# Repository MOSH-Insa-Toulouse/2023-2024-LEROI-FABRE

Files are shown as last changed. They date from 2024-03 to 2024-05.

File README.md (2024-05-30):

# Projet MOSH
## Par Quentin et Laetitia 🥇
### ~~Le meilleur binôme~~ (il faut pas le dire) 



Cohésion d'équipe ☑️
## Diagramme du projet
```mermaid
graph TD;
    A[Capteur Graphite]-->B((Arduino Uno));
    F[Capteur Flex]-->B((Arduino Uno));
    G[Potentiomètre]-->B((Arduino Uno));
    B((Arduino Uno))-->D[Ecran LCD];
    B((Arduino Uno))-->C[Module Bluetooth];
    C[Module Bluetooth]-.->E[App Android];

```

<details>
<summary>  Etapes du projet MOSH :tada:  </summary>
  
  - [x] Attribution des inputs de l'arduino aux différents capteurs
  - [X] Electronique Analogique
  - [x] Schématique KiCad  
  - [x] Routage KiCad
  - [x] Impression du cricuit
  - [x] Percage
  - [X] Montage des capteurs sur le circuit imprimé (par Cathy, MERCIII)
  - [X] Code Arduino
  - [X] App Android
  - [X] Création du banc de test
  - [X] Création de la datasheet
        
</details>

# Quel est ce projet ?

Ce projet consiste en...

<details>
<summary> la création d'un capteur Graphite. </summary>
Un capteur graphite, c'est tout simplement un morceau de papier où l'on colorie une zone à l'aide d'un crayon à papier. Il permet de mesurer des variations de résistance lorqu'on le déforme. Voici la forme de capteur que nous utilisons : 

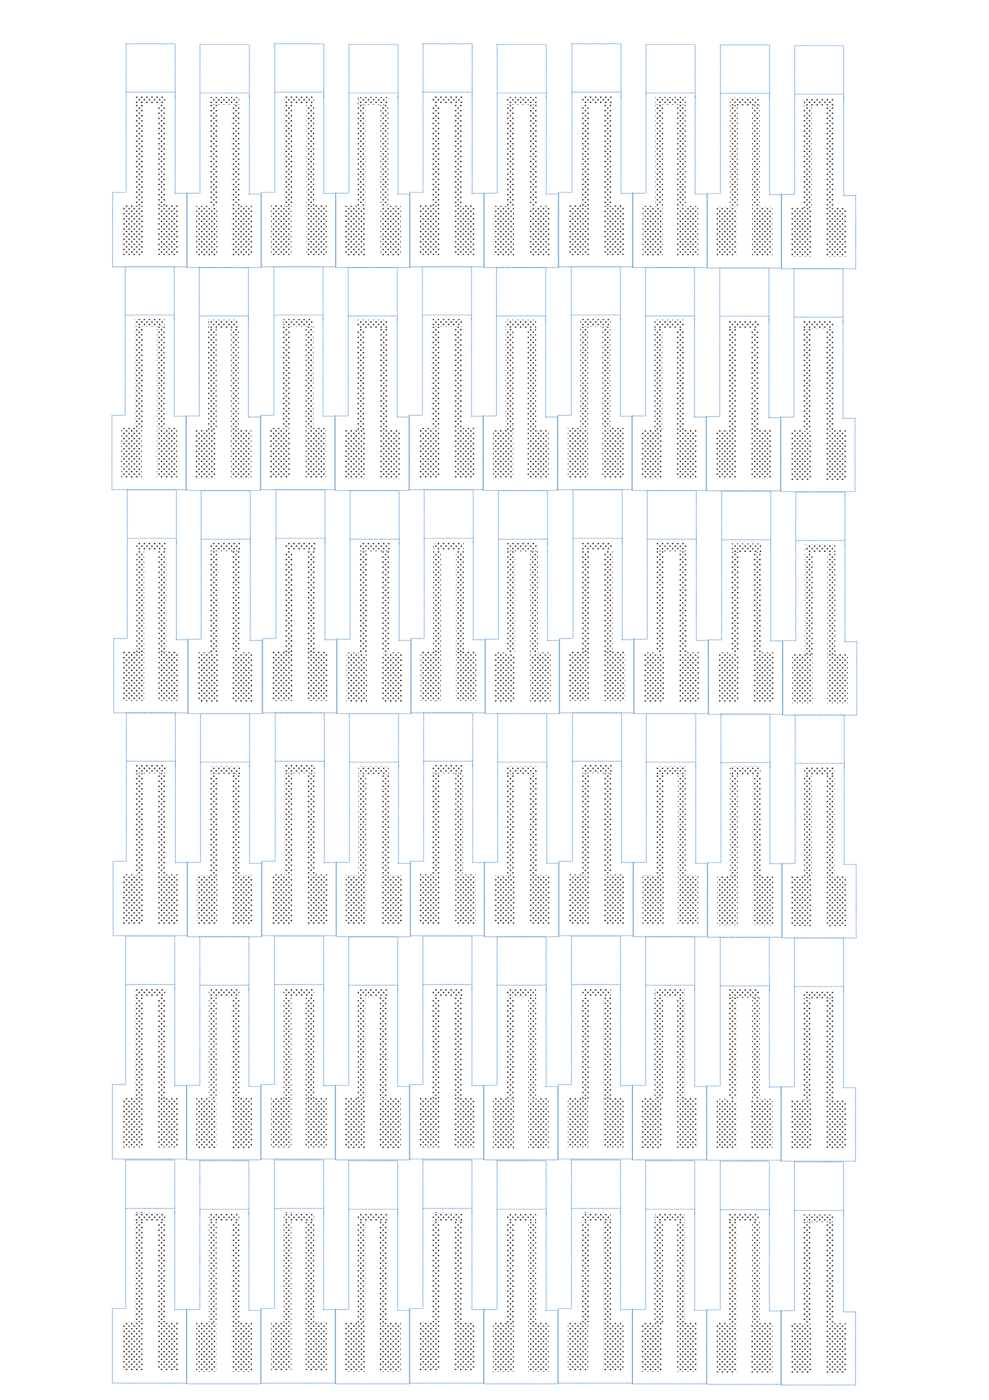
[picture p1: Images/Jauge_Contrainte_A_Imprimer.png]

</details>

<details>
<summary> la création d'un shield Arduino. </summary>
Cela permet d'effectuer les acquisitions des données envoyées par notre capteur (des variations de tensions que nous pouvons traduire en résistance !). 
Nous y implémenterons également un capteur Flex dont voici la datasheet : (insérer la datasheet), un écran LCD pour afficher les données du capteur graphite ou du capteur flex, un potentiomètre qui permettra à l'utilisateur de naviguer dans un menu qui permet d'afficher les données du capteur graphite ou du capteur flex, un potentiomètre numérique qui permettra d'ajuster une résistance pour la maniulation des données du capteur graphite,... 

Pour cela, il nous faut créer le shield sous KiCad, le faire imprimer, percer le trous, et y monter nos capteurs.
</details>

<details>
<summary> la création d'un code Arduino. </summary>
Le code permettra de commander le microcontrôleur Arduino Uno : gestion des données, commnication Bluetooth (voir App android), choix de la résistance du potentiomètre numérique, affichage sur l'écran LCD...
</details>

<details>
<summary> la création d'une App Android. </summary>
Notre projet s'accompagne également d'une App Android : grâce à la communication Bluetooth, nous pouvons afficher sur un smartphone des graphiques des données enregistrées par nos deux capteurs. Nous créons l'app sur  MIT app Inventor (https://community.appinventor.mit.edu/).
</details>

<details>
<summary> tout ça pour l'élaboration d'une Datasheet ! </summary>
L'objectif final, le graal du projet, c'est de rédiger une datasheet du capteur Graphite. Le banc de test et notre code arduino nous ont permis de réaliser toutes les mesures. 
</details>

# Je veux aller voir...
 __(cliquez)__ 

## L'Electronique Analogique  [Clique](https://github.com/MOSH-Insa-Toulouse/2023-2024-LEROI-FABRE/tree/main/LTSpice%20-%20Electronique%20Analogique)
<details>
<summary> Explications. </summary>
    
Vous trouverez dans ce dossier le circuit analogique du capteur graphite. Il y a un amplificateur transimpédance et un filtre qui permettent d'obtenir un signal utilisable. En effet, le signal délivré par le capteur sans ce circuit est trop faible : il a un courant moyen de 100nA, donc il faudrait un microcontrôleur très précis pour pouvoir détecter des variations sur ce signal. C'est pourquoi nous l'amplifions. 

Les filtres sont nécessaires afin d'élminer les fréquences 50Hz dans lesquelles nos environnements sont baignés (à cause du réseau électrique), et d'autres fréquences parasites.

Voici un schéma, qui est une capture d'écran de nos simulations LTSpice : 


Les parties qui servent à filtrer sont dans les rectangles :
- le rectangle vert, avec une capacité de 100n, sert à filtrer le signal d'entrée. C'est un filtre passe-bas. Sa fréquence de transition est d'envirion 159Hz (formule f=1/(2*pi*R*C)). Il permet donc d'éliminer le bruit qui pourrait naître à l'entrée du circuit.
- le rectangle violet a une fonction similaire : c'est un filtre passe-bas, qui permet de filtrer le bruit en sortie, de fréquence de transition de 1591Hz.
- le rectangle rouge entoure le filtre passe-bas qui permet de filtrer le bruit environnant à 50Hz.

Le reste du circuit permet de réaliser l'amplifictation du signal. 

</details>

## Le KiCad ! [C'est ici](https://github.com/MOSH-Insa-Toulouse/2023-2024-LEROI-FABRE/tree/main/KiCad)

<details>
<summary> Explications. </summary>
    
Nous avons créé des empreintes KiCad pour notre capteur graphite, et pour les éléments qui ne sont pas déjà disponibles dans a librairie intégrée KiCad. Vous pouvez les retrouver dans le dossier KiCad. 

Nous avons ces contraintes pour la fabrication de nos shields : 
- largeur de routage de 0.5mm minimum.
- largeur de 0.5mm minimum entre différents routages afin d'assurer l'isolation électrique.
- nous avons élargi les pads du module bluetooth, de l'encodeur rotatoire, de l'écran OLED et des connecteurs du header à 2*2.54 (oval).
- vias de 0.8mm, cercle de 2.54mm.

Cela assure le fonctionnement du shield, et nous permet de percer les vias facilement.

| :exclamation:  ATTENTION CHERS COLLEGUES   |
|----------------------------------------------|

Nous avons commis des erreurs sur le fichier KiCad ! Chers ingénieurs/techniciens/instrumentateurs qui réalisez ce projet en suivant nos pas, n'oubliez pas de relier le MCP au reste du circuit !! Et n'inversez pas les pattes du LTC !!

</details>

## Non, je veux voir le code Arduino [Juste là](https://github.com/MOSH-Insa-Toulouse/2023-2024-LEROI-FABRE/tree/main/Arduino%20V2/projet_capteur) 

<details>
<summary> Explications. </summary>

Ce code a toutes ces fonctionalités :
- gère l'affichage sur l'écran OLED via une fonction.
- l'interruption DoEncodeur est réalisée à chaque fois que quelqu'un tourne l'encodeur rotatoire : l'utilisateur tourne l'encodeur, et au prochain tick de clock, linterruption sera réalisée. Elle permet d'ajouter +1 à la valeur que compte l'encodeur. Celui-ci sert à gérer le menu de l'écran OLED. Le principe est que lorsque nous tournons l'encodeur, c'est pour changer l'affichage de l'écran. Ainsi, si la valeur comptée par l'encodeur est paire nous aurons un afichage (capteur Flex), et s'il est impair, nous aurons un autre affichage (capteur graphite).
- la communication Bluetooth : nosu envoyons les données du capteur graphite ou du capteur flex à une application MIT via bluetooth. Si le module bluetooth recoit 1 de la part de l'application, c'est que l'utilisateur a appuyé sur le bouton "capteur flex". S'il recoit 2, c'est que l'utilisateur a appuyé sur "capteur graphite" dans l'app.
- la modification de la résistance du potentiomètre numérique : cela permet de calibrer le signal renvoyé par le capteur graphite.

  </details>

## Je préfère voir l'app Android [Okay...](https://github.com/MOSH-Insa-Toulouse/2023-2024-LEROI-FABRE/tree/main/App%20Android)
<details>
<summary> Explications. </summary>

Le projet s'accompagne d'une App qui fonctionne sur les téléphones android. Elle permet d'abotenir en temps réel les mesures du capteur graphite ou du capteur flex. Cela fonctionne grâce à une connexion Bluetooth. L'application est simple d'utilisation pour l'utilisateur.

Le code de l'application se fait sous [MIT App Inventor.](https://community.appinventor.mit.edu/) C'est un site gratuit simple dutilisation. Le code se fait via des blocks que l'utilisateur ajoute petit à petite, c'est très intuitif.
Voici une photo de l'application en fonctionnement :



</details>

## La Datasheet [Elle est au chaud ici](https://github.com/MOSH-Insa-Toulouse/2023-2024-LEROI-FABRE/tree/main/Datasheet)

## Des photos du projet, plutôt ! 📷 
<details>
<summary> Attention, époustouflant. </summary>

| :boom: BANG               |
|:----------------------------|
| Le capteur fonctionne ! On capte bien des variations quand on bouge le capteur Graphite |



| :boom: BANG               |
|:----------------------------|
| Le projet, c'est aussi beaucoup de fils lors de la phase de tests ! On a nettoyé tous ces fils ensuite, et c'était tout de suite beaucoup plus clair..! |



| :boom: BANG               |
|:----------------------------|
| Une des erreurs du fichier KiCad... |

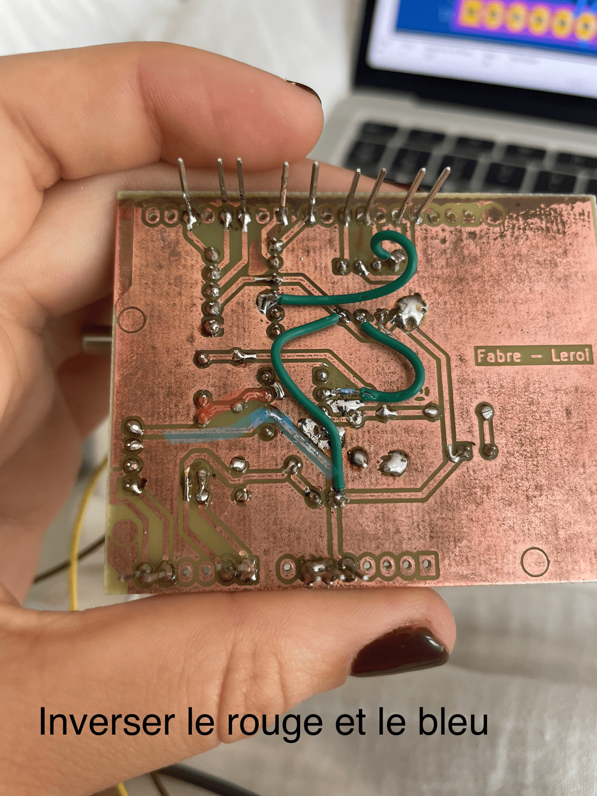
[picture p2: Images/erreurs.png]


| :boom: BANG               |
|:----------------------------|
| N'oubliez pas de faire un poisson d'avril à votre binôme |



| :boom: BANG               |
|:----------------------------|
| Quelle belle application Android |



| :boom: BANG               |
|:----------------------------|
| Petit selfie de fin de projet |

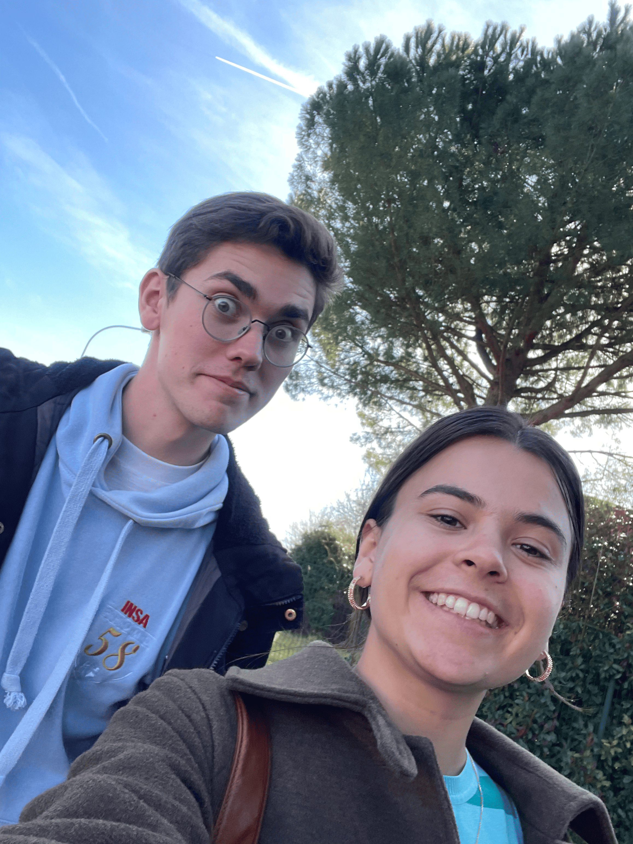
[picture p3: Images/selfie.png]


| :boom: BANG               |
|:----------------------------|
| C'était un projet à en tomber par terre |



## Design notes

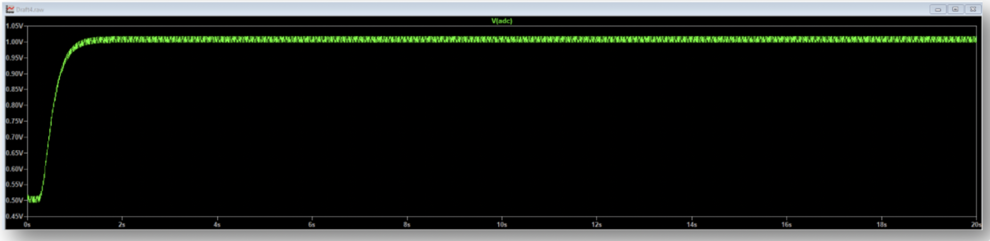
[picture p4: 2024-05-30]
LTSpice - Electronique Analogique/transitoire.png

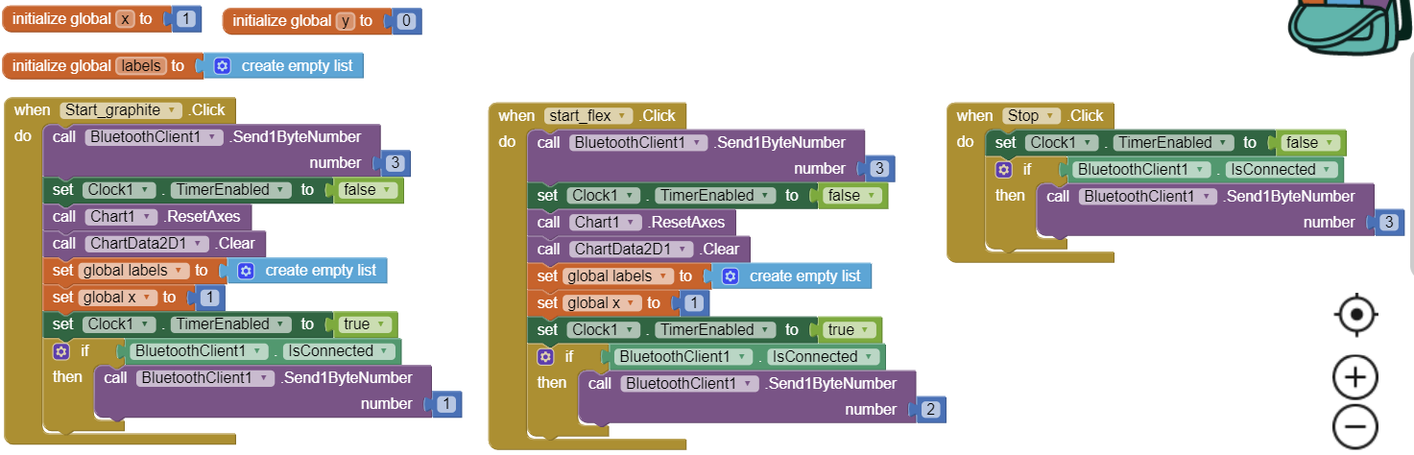
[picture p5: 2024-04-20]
App Android/MIT App Inventor Start et Stop Code.png

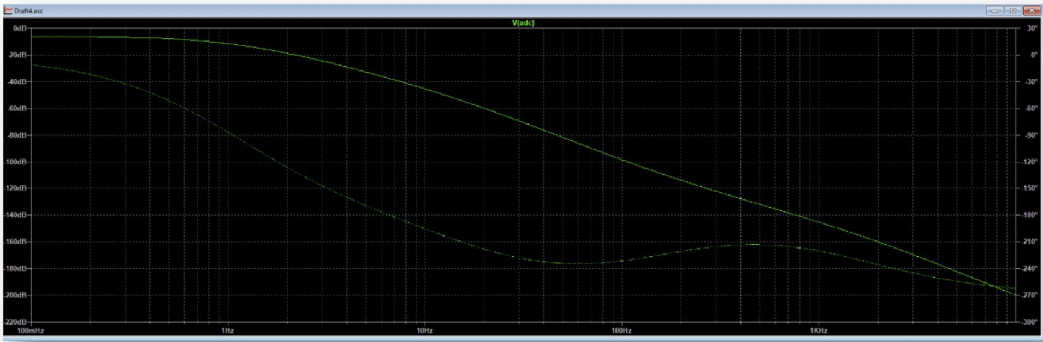
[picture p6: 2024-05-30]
LTSpice - Electronique Analogique/ac.png

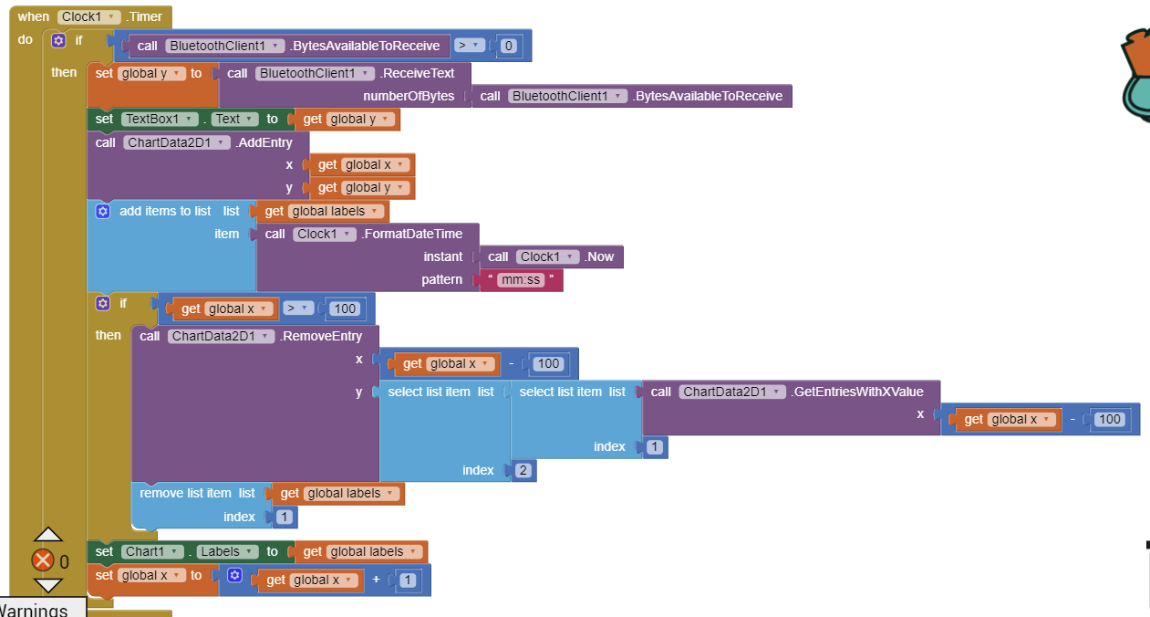
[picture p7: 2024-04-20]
App Android/MIT App Inventor Graphique.png

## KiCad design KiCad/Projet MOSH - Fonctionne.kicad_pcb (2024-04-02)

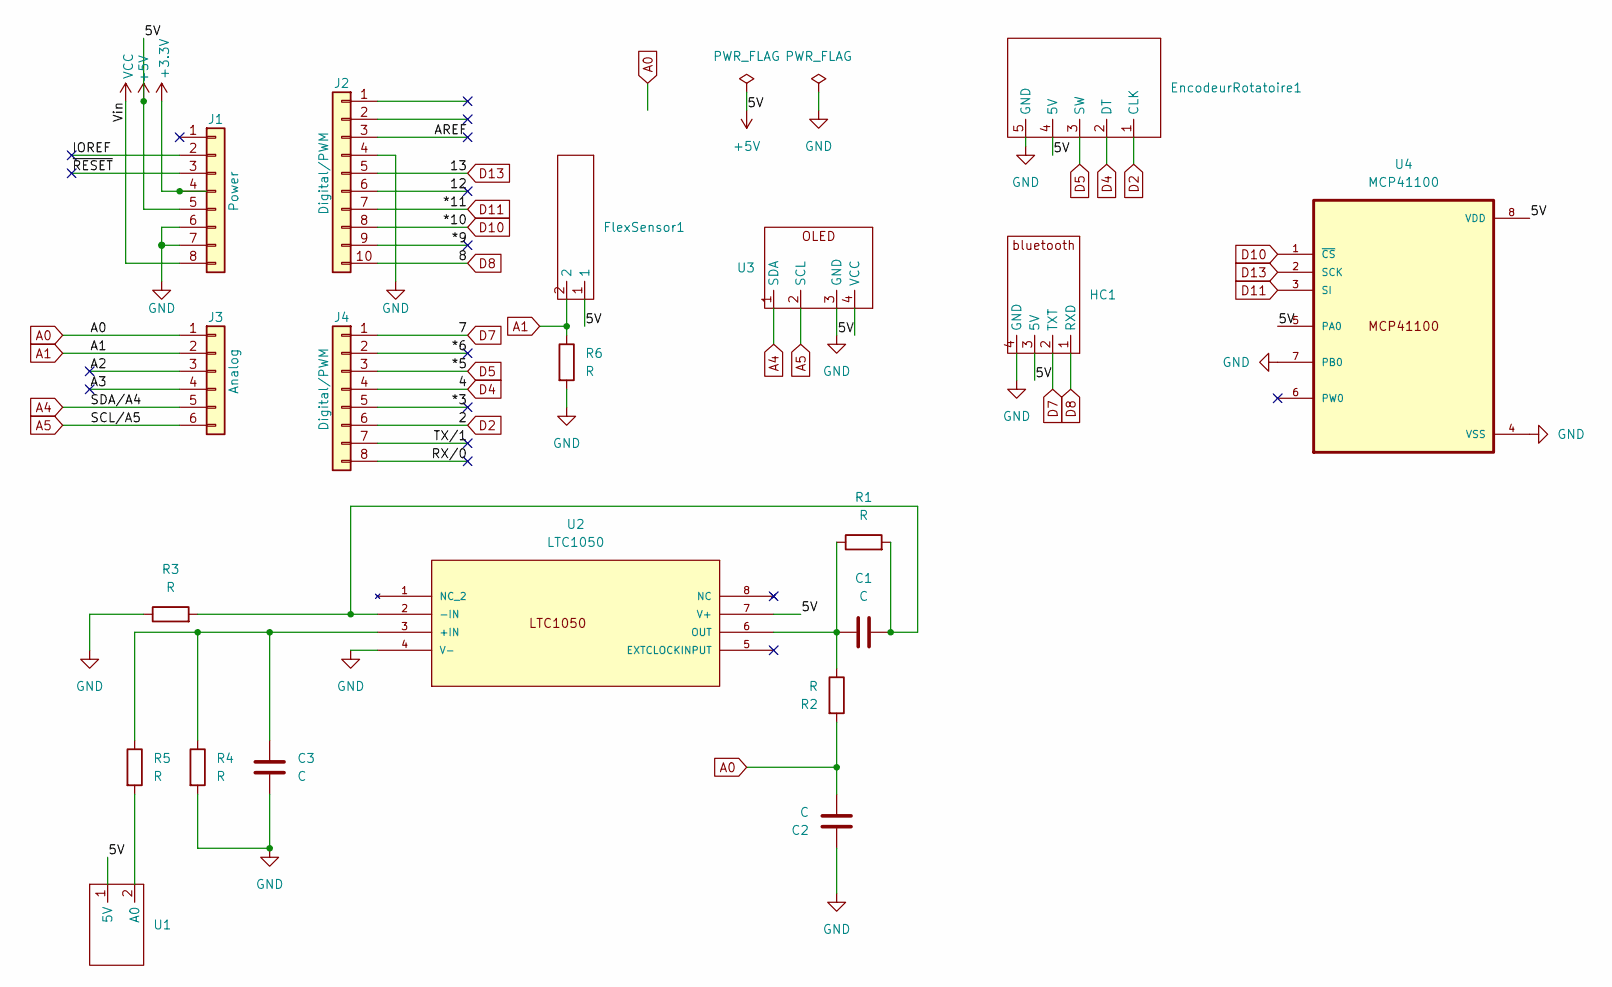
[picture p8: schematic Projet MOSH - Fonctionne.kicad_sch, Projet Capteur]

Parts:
C1: C; Capa rouge
C2, C3: C; Capa jaune
EncodeurRotatoire1: KY-040
FlexSensor1: Capteur FLEX
HC1: Bluetooth HC-05
J1: Power; PinSocket_1x08_P2.54mm_Vertical
J2: Digital/PWM; PinSocket_1x10_P2.54mm_Vertical
J3: Analog; PinSocket_1x06_P2.54mm_Vertical
J4: Digital/PWM; PinSocket_1x08_P2.54mm_Vertical
R1, R2, R3, R4, R5, R6: R; R 65 2
U1: capteur graphite
U2: LTC1050; LTC1050 et MCP; MANUFACTURER_PART_NUMBER ltc1050hs8
U3: OLED SCREEN
U4: MCP41100; LTC1050 et MCP

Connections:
+3V3: J1.4
+5V: EncodeurRotatoire1.4 (5V), FlexSensor1.1, HC1.3 (5V), J1.5, U1.1 (5V), U2.7 (V+), U3.4 (VCC), U4.5 (PA0), U4.8 (VDD)
/12: J2.6
/*3: J4.5
/*6: J4.2
/*9: J2.9
/A2: J3.3
/A3: J3.4
/AREF: J2.3
/IOREF: J1.2
/RX/0: J4.8
/TX/1: J4.7
/~RESET: J1.3
A0: C2.2, J3.1, R2.2
A1: FlexSensor1.2, J3.2, R6.1
A4: J3.5, U3.1 (SDA)
A5: J3.6, U3.2 (SCL)
D2: EncodeurRotatoire1.1 (CLK), J4.6
D4: EncodeurRotatoire1.2 (DT), J4.4
D5: EncodeurRotatoire1.3 (SW), J4.3
D7: HC1.2 (TXT), J4.1
D8: HC1.1 (RXD), J2.10
D10: J2.8, U4.1 (~CS)
D11: J2.7, U4.3 (SI)
D13: J2.5, U4.2 (SCK)
GND: C2.1, C3.2, EncodeurRotatoire1.5 (GND), HC1.4 (GND), J1.6, J1.7, J2.4, R3.1, R4.2, R6.2, U2.4 (V-), U3.3 (GND), U4.4 (VSS), U4.7 (PB0)
unnamed: R5.2, U1.2 (A0)
unnamed: C3.1, R4.1, R5.1, U2.3 (+IN)
unnamed: C1.2, R1.2, R3.2, U2.2 (-IN)
unnamed: C1.1, R1.1, R2.1, U2.6 (OUT)
VCC: J1.8

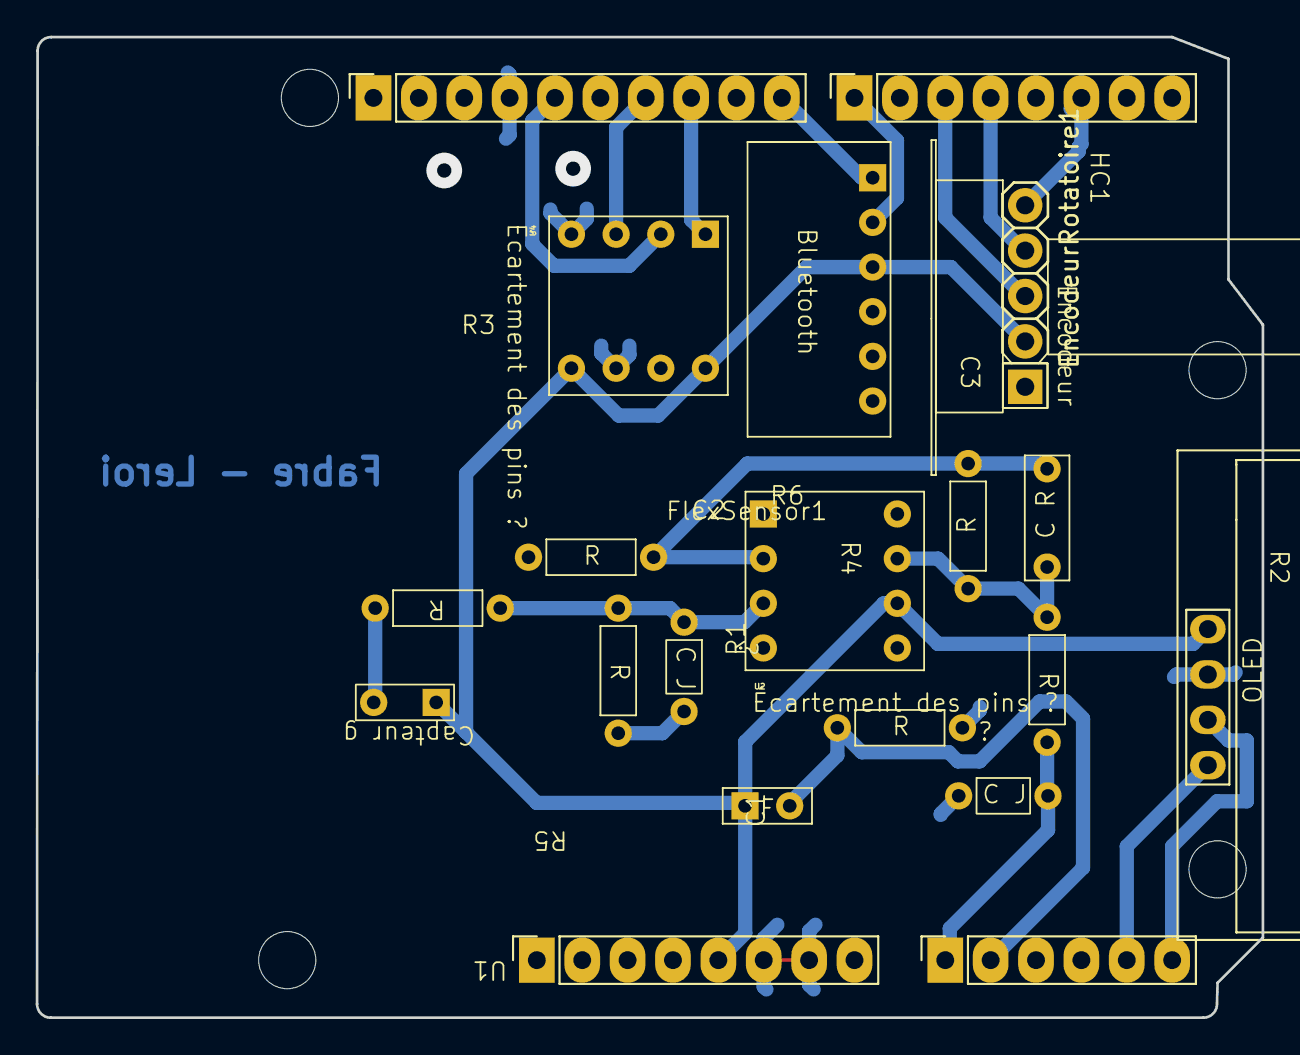
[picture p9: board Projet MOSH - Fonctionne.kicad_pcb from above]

Board: 2 copper layers, 68.6 x 54.9 mm, 24 parts (0 on the bottom side), 18 nets.

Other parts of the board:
MH1, MH2, MH3, MH4: MountingHole_3.2mm

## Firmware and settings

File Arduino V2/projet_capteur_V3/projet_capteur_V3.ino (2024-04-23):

#include <Adafruit_SSD1306.h>
#include <String.h>
#include <SoftwareSerial.h>
#include <WString.h>
#include <SPI.h>

#define nombreDePixelsEnLargeur 128  // Taille de l'écran OLED, en pixel, au niveau de sa largeur
#define nombreDePixelsEnHauteur 64   // Taille de l'écran OLED, en pixel, au niveau de sa hauteur
#define brocheResetOLED -1           // Reset de l'OLED partagé avec l'Arduino (d'où la valeur à -1, et non un numéro de pin)
#define adresseI2CecranOLED 0x3C     // Adresse de "mon" écran OLED sur le bus i2c (généralement égal à 0x3C ou 0x3D)
#define encoder0PinA 2               //CLK Output A Do not use other pin for clock as we are using interrupt
#define encoder0PinB 4               //DT Output B
#define PinCapteur A0
#define PinFlex A1
#define CsPin 10 // pin du Chip Select du MCP

#define rxPin 7 //Bluetooth
#define txPin 8 //Bluetooth
#define baudrate 9600

float R1= 100000.0;
float R3 = 100000.0;
float R6 = 100000.0;
float R2 = 1000.0;
float R5 = 10000.0;
float calibre=0.000001;//en MOhm
float Vcc=5.0;
float Voltage =0.0;
float Resistance = 0.0;

SoftwareSerial HC05(rxPin, txPin);

//relatif au MCP

const int  maxPositions    = 256;     // wiper can move from 0 to 255 = 256 positions
const long rAB             = 92500;   // 100k pot resistance between terminals A and B, 
                                      // mais pour ajuster au multimètre, je mets 92500
const byte rWiper          = 125;     // 125 ohms pot wiper resistance
const byte pot0            = 0x11;    // pot0 addr // B 0001 0001
const byte pot0Shutdown    = 0x21;    // pot0 shutdown // B 0010 0001

Adafruit_SSD1306 ecranOLED(nombreDePixelsEnLargeur, nombreDePixelsEnHauteur, &Wire, brocheResetOLED);
int tailleDeCaractere = 2;
volatile unsigned int Encodeur = 0;

void setup() {
  Serial.begin (baudrate);

  pinMode(PinCapteur, INPUT);  //Pin relié au capteur
  pinMode(PinFlex, INPUT);     //Pin relié au Flex sensor

  pinMode(encoder0PinA, INPUT);  //Pin relié à l'encodeur : CLK
  pinMode(encoder0PinB, INPUT);  //Pin relié à l'encodeur : DT

  /*
  pinMode(5, INPUT); //Pin relié à l'encodeur : SW
  
  pinMode(10, INPUT); //Pin relié au Potentiomètre MCP41100 -CS 
  pinMode(11, OUTPUT); //Pin relié au MCP41100 SI
  pinMode(13, OUTPUT); //Pin relié au MCP41100 SCK*/

  // Initialisation de l'écran OLED
  if (!ecranOLED.begin(SSD1306_SWITCHCAPVCC, adresseI2CecranOLED)) {
    Serial.print("échec d'initialisation");
    while (1)
      ;
  }  // Arrêt du programme (boucle infinie) si échec d'initialisation

  //Initialisation Bluetooth
  pinMode(txPin,OUTPUT); 
  pinMode(rxPin,INPUT);
  HC05.begin(9600);


  // initialisation utile pour l'encodeur rotatoire
  digitalWrite(encoder0PinA, HIGH);       // turn on pullup resistor
  digitalWrite(encoder0PinB, HIGH);       // turn on pullup resistor
  attachInterrupt(0, doEncoder, RISING);  // encoder pin on interrupt 0 - pin2

  //initialisation MCP

  digitalWrite(CsPin, HIGH);        // chip select default to de-selected
  pinMode(CsPin, OUTPUT);           // configure chip select as output
  SPI.begin();
}

void setPotWiper(int addr, int pos) {
  pos = constrain(pos, 0, 255);            // limit wiper setting to range of 0 to 255
  digitalWrite(CsPin, LOW);                // select chip
  SPI.transfer(addr);                      // configure target pot with wiper position
  SPI.transfer(pos);
  digitalWrite(CsPin, HIGH);               // de-select chip

  // print pot resistance between wiper and B terminal
  long resistanceWB = ((rAB * pos) / maxPositions ) + rWiper;
  /*Serial.print("Wiper position: ");
  Serial.print(pos);
  Serial.print(" Resistance wiper to B terminal: ");
  Serial.print(resistanceWB);
  Serial.println(" ohms");*/
}

float Capteur_Flex()
{
  float R = -0.2636*analogRead(PinFlex)+185.9;
  return R;
}

float Capteur_Graphite()
{
  float Voltage=analogRead(PinCapteur)*5.0/1024.0;
  float Resistance=((R1*((R2+R3)/R2)*(Vcc/Voltage))-R5-R1)*calibre;
  return Resistance;

}

void Affichage_OLED() {

  ecranOLED.clearDisplay();  // Effaçage de l'intégralité du buffer
  ecranOLED.setTextSize(tailleDeCaractere);
  ecranOLED.setTextColor(SSD1306_WHITE);  //Couleur du texte : blanc
  ecranOLED.setCursor(0, 0);              // Déplacement du curseur en position (0,0), c'est à dire dans l'angle supérieur gauche
  ecranOLED.display();                    //permet d'effacer l'affichage précédent


if (Encodeur % 2) {  //boucle permettant de naviguer dans le menu : si l'encodeur est sur une position paire, il affiche le capteur flex, et s'il est sur une position impaire, il affiche le capteur graphite.

    float Res = Capteur_Flex();
    int Angle=((Res-30)*2);

ecranOLED.println(F("Capteur Flex :"));
ecranOLED.print(F("R :"));
ecranOLED.println(Res);
ecranOLED.print(F("Angle :"));
ecranOLED.print(Angle);
ecranOLED.display();

  } else {

    float ResG = Capteur_Graphite();
    ecranOLED.print(F("Capteur Graphite :    "));
    ecranOLED.print(ResG);
    ecranOLED.display();

  }
delay(200);
}


int usebyte;
int i;

void EnvoiBT (int usebyte)
{
// put your main code here, to run repeatedly:
  Affichage_OLED();
     //Pour vérif qu'on est dans la boucle
  
  Serial.println(usebyte);
  float Mes=0;
  if (usebyte!=3)
  {
  
    if (usebyte == 2)
    {
      Mes = Capteur_Flex();
      int Angle=((Mes-30)*2);

    }
    if (usebyte == 1)
    {
      Mes=Capteur_Graphite();
  
    }

    //Serial.println(Mes);
    char Val[10];
    dtostrf(Mes, 5, 2, Val);
    HC05.write(Val);
    //Serial.println("fini");
    delay(500);

 }
  }



void loop() {
  setPotWiper(pot0, R2);  
    Affichage_OLED();
  if (HC05.available()) 
  {
    int Byte = HC05.read();
     
    EnvoiBT(Byte);

    int Byte2 = Byte;
  }
  else
  {
    int Byte = HC05.read();

  }

}

//définition de la fonction d'interruption. Elle est exécutée dès que la pin 2 est sur HIGH, c'est-à-dire dès que l'on tourne l'encodeur.
//à voir : peut-on supprime la partie où on fait Encodeur--? On pourrait seulement augmenter le chiffre..?
void doEncoder() {
  if (digitalRead(encoder0PinB) == HIGH) {
    Encodeur++;
  } else {
    Encodeur--;
  }
}

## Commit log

2024-03-11 Create KiCad
2024-03-11 Projet KiCad : démarrer le routage
    [Projet MOSH.kicad_pcb]
2024-03-12 Add files via upload
    Début de routage
2024-03-13 Modification du PCB
    [Projet MOSH - Fonctionne peut etre.kicad_pcb]
2024-03-13 Fonctionne presque ! Juste deux zones GND à connecter et ce sera bon
    [Projet MOSH - Fonctionne peut etre.kicad_pcb, Projet MOSH - Fonctionne peut etre.kicad_sch, Projet MOSH - Fonctionne peut etre_.kicad_sch]
2024-03-13 Create résistance.kicad_mod
    changement résistance
2024-03-20 Wow
    It is workiiiiiing
    [Projet MOSH - Fonctionne peut etre.kicad_pcb]
2024-03-20 Il manque a relier les vias
    [Projet MOSH - Fonctionne peut etre.kicad_pcb]
2024-03-26 Graph ok et Connexion BT OK, mais pas encore d'affichage des données par BT
2024-04-18 Photo page de garde
2024-04-18 Ajout image page de garde
2024-04-18 Ré organisation
    [Projet MOSH - Fonctionne peut etre_.kicad_sch, Projet MOSH - Fonctionne.kicad_pcb, Projet MOSH - Fonctionne.kicad_sch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]
2024-04-18 Simple organisation
    [Projet MOSH - Fonctionne peut etre_.kicad_sch]
2024-04-20 Modif Images
    [Projet MOSH - Fonctionne peut etre_.kicad_sch]
2024-04-23 Arduino, encore voir les pics avant d'avoir des mesures
2024-05-07 Finished code and results
    [Resistances.xlsx]
2024-05-29 Résultats terminés
    [Resistances.xlsx]
